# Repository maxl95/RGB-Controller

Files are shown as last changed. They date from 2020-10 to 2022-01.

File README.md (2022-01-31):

# RGB-Controller
This is a low cost and tasmota compatile RGB-Controller as an alternative to MagicHome devices.
~~Everything is untested until now. The first prototypes are orderd.~~ 

The first pcbs are tested (see pics below). Everything works fine.

**This version is no longer maintained.** 
I recommend the RGBW version: [RGBW-Version](https://github.com/maxl95/RGBW-Controller)

# Some specs:
- operating voltage 12V (becaus of the mini360)
- max current per channel (color) 5A in theory 
- fully compatible with [Tasmota](https://github.com/arendst/Tasmota)
- price/piece around 5.60€
- dimensions 20mm x 35mm

# Tasmota template
> {"NAME":"RGB-Controller DIY","GPIO":[1,1,1,1,1,417,1,1,416,418,1,1,1,1],"FLAG":0,"BASE":18}

# known bugs:
- ~~GPIO15 is not connected to GND so ESP won't startup~~ --> fixed
- ~~Solder Mask isn't on via's, so may be a risk of short circuit~~ --> fixed
- ~~Track width of RGB strip supply is a bit too small, could be more~~ --> fixed

# Pictures:
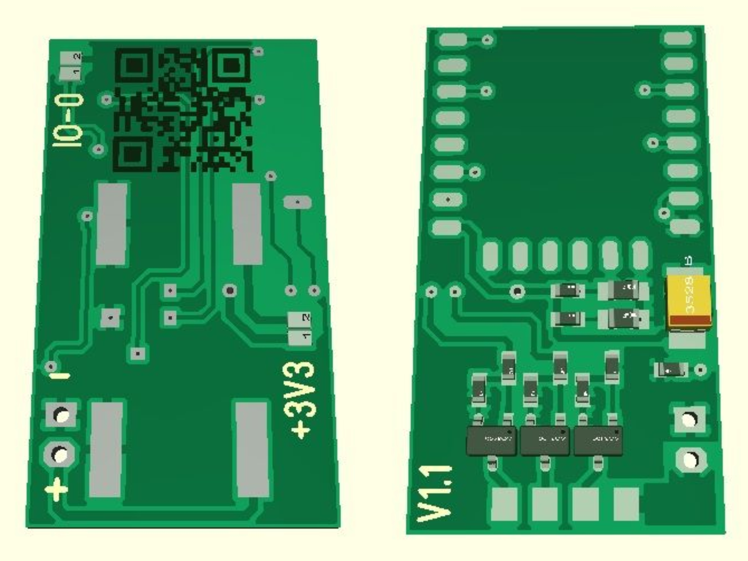
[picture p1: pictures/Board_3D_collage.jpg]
Board3D

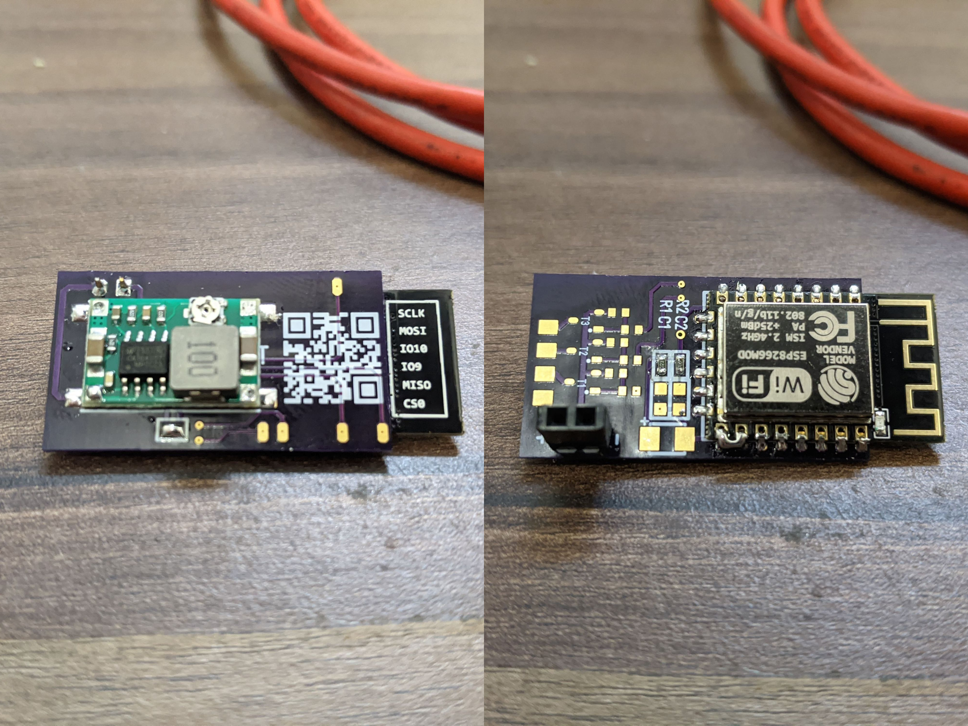
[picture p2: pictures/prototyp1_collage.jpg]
Prototyp

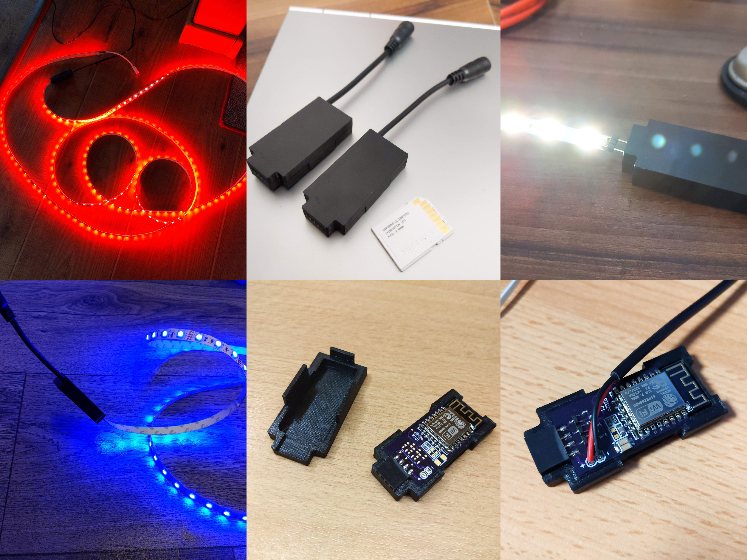
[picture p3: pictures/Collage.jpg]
Collage


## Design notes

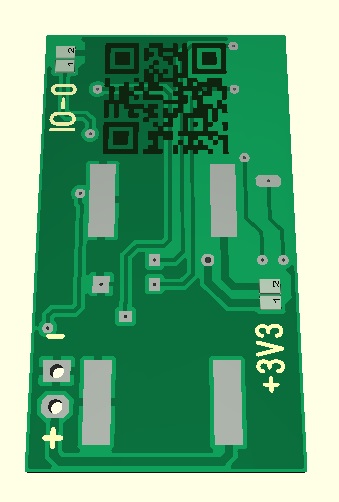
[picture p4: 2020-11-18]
pictures/Board_3D_Bottom.jpg

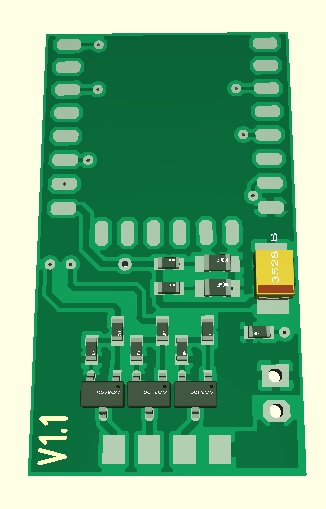
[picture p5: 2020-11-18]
pictures/Board_3D_Top.jpg

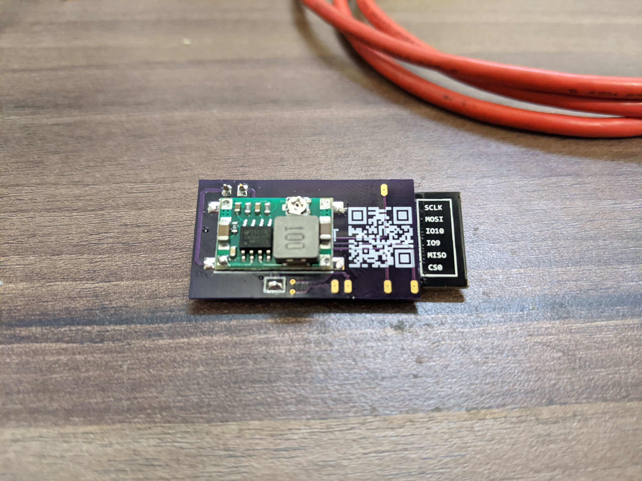
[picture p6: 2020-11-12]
pictures/prototyp_bottom.jpg

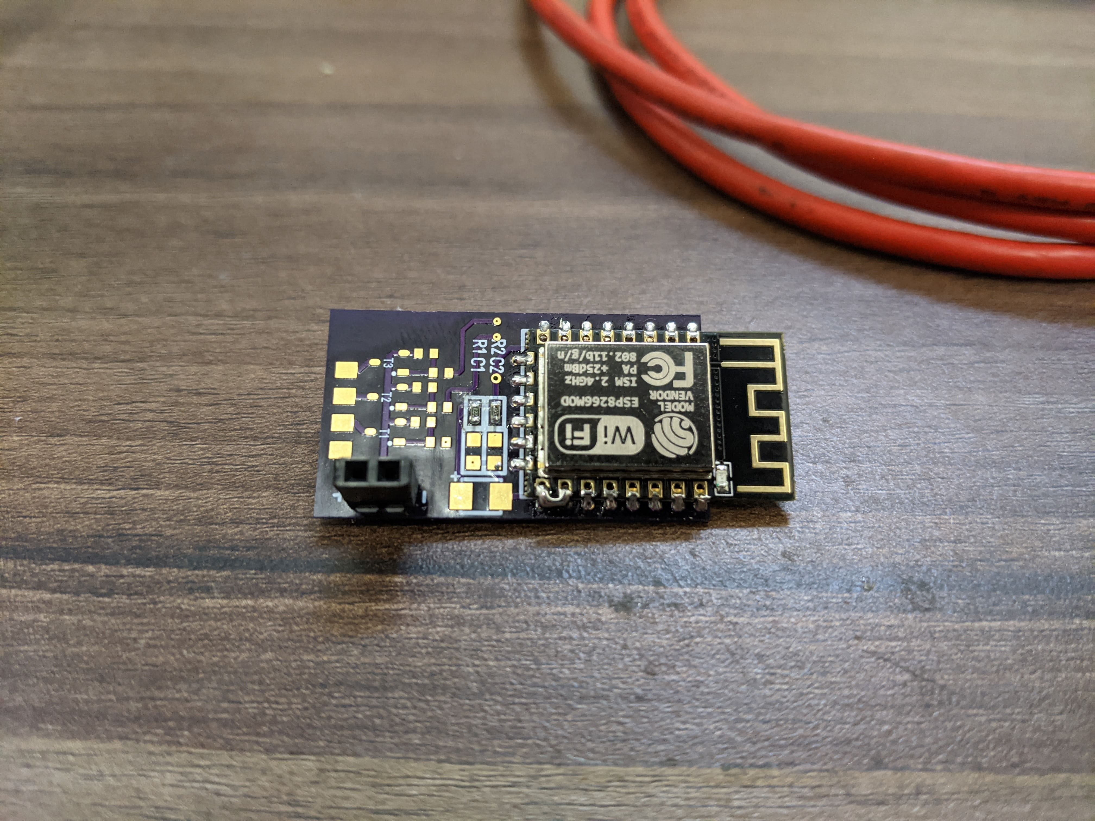
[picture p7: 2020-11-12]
pictures/prototyp_top.jpg

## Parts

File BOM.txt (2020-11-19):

Pos.							URL
~~~~~~~~~~~~~~~~~~~~~~~~~~~~~~~~~~~~~~~~~~~~~~~~~~~~~~~~~~~~~~~~~~~~~~~~~~~~~~~~~~~~~~~~~~~~~~~~~~~~~~~~~~~~~~~~~~~~~~~~~~~~~~~~~~~~~~~~~~~~~~~~~~~~
47µF 16V Tantal Kondensator 3528 (B 16V47UF 476)	https://de.aliexpress.com/item/4001241518347.html?spm=a2g0s.8937460.0.0.41b92e0eFXfjOQ
Step-Down Modul Mini360					https://de.aliexpress.com/item/4001080047766.html?spm=a2g0s.8937460.0.0.41b92e0eFXfjOQ
AO3400 Mosfet SOT23					https://de.aliexpress.com/item/4001035147965.html?spm=a2g0s.8937460.0.0.41b92e0eFXfjOQ
100k 0603 SMD Widerstand				https://de.aliexpress.com/item/32858644837.html?spm=a2g0s.8937460.0.0.41b92e0eFXfjOQ
100nF 0805 SMD Kondensator				https://de.aliexpress.com/item/32964553793.html?spm=a2g0s.8937460.0.0.41b92e0eFXfjOQ
330R 0603 SMD Widerstand				https://de.aliexpress.com/item/32858644837.html?spm=a2g0s.8937460.0.0.41b92e0eFXfjOQ
10k 0603 SMD Widerstand					https://de.aliexpress.com/item/32858644837.html?spm=a2g0s.8937460.0.0.41b92e0eFXfjOQ
ESP12F							https://www.aliexpress.com/item/-/4000539532547.html?spm=a2g0s.8937460.0.0.41b92e0eFXfjOQ
DC Jack Female						https://de.aliexpress.com/item/32966940042.html?spm=a2g0s.8937460.0.0.41b92e0eFXfjOQ

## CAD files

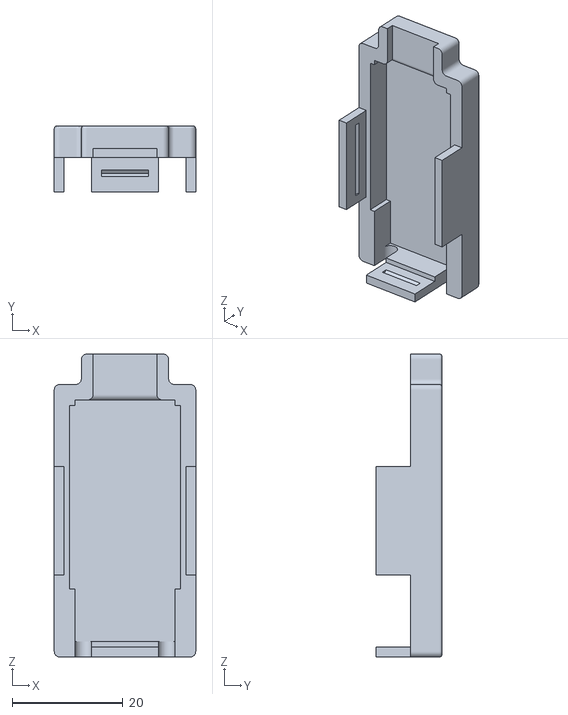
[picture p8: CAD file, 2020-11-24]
casing/top_w_2_holes.STL
25.6 x 12.0 x 54.8

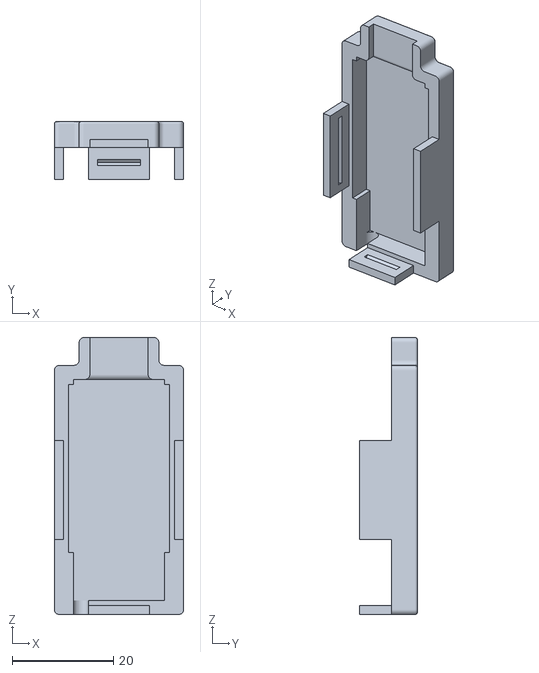
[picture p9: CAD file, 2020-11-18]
casing/top.STL
25.6 x 11.5 x 54.8

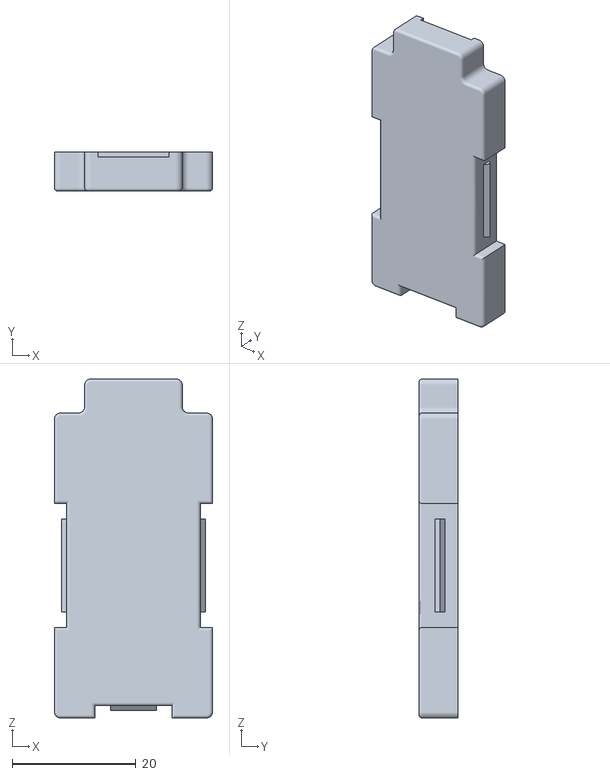
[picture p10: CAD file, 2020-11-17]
casing/bottom.STL
25.6 x 6.30 x 54.8

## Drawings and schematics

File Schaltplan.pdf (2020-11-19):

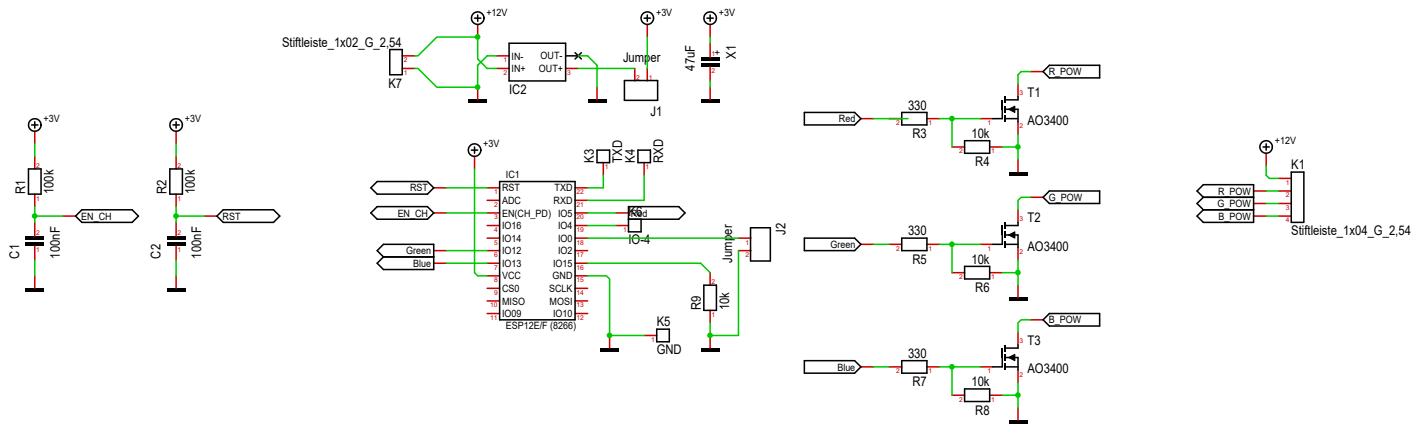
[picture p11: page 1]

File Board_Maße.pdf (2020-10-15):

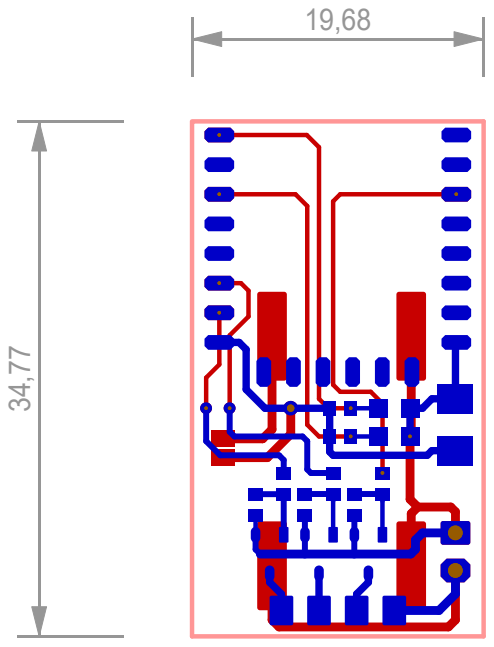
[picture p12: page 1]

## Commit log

2020-10-15 Add files via upload
    initial commit
    [RGB-Controller.GBL, RGB-Controller.GBO, RGB-Controller.GBS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]
2020-11-17 update layout file
    [RGB-Controller.GBL, RGB-Controller.GBO, RGB-Controller.GBS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]
2020-11-17 update gerber files
    [RGB-Controller.GBL, RGB-Controller.GBO, RGB-Controller.GBS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]
2020-11-17 added casing
    [bottom.STL, top.STL]
2020-11-18 update casing
    [top.STL]
2020-11-18 new pics and schematics update
2020-11-19 changed tantal capacitor to 47uF/16V
2020-11-19 changed capacitator in schematics
2020-11-19 changed value of R9 in schematics
2020-11-24 added second casing top with two holes for some extra features like buttons etc
    [top_w_2_holes.STL]
2020-11-24 updated Gerber-files for JLCPCB and OSHPark
    [RGB-ControllerV1.1.GBO]
